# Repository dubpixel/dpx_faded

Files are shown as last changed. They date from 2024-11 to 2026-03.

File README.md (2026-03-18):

<!-- Improved compatibility of back to top link: See: https://github.com/othneildrew/Best-README-Template/pull/73 -->

<!--  *** Thanks for checking out the Best-README-Template. If you have a suggestion that would make this better, please fork the repo and create a pull request or simply open an issue with the tag "enhancement". Don't forget to give the project a star! Thanks again! Now go create something AMAZING! :D -->

<!-- /// d   u   b   p   i   x   e   l  ---  f   o   r   k   ////--v0.5.0 -->
<!--this has additionally been modifed by @dubpixel for hardware use -->
<!--search dpx_faded.. search & replace is COMMAND OPTION F -->

<!--todo add small product image thats not in a details tag -->
<!--igure out how to get the details tag to properly render in jekyll for gihub pages.-->

<!-- PROJECT SHIELDS -->
<!--
*** I'm using markdown "reference style" links for readability.
*** Reference links are enclosed in brackets [ ] instead of parentheses ( ).
*** See the bottom of this document for the declaration of the reference variables
*** for contributors-url, forks-url, etc. This is an optional, concise syntax you may use.
*** https://www.markdownguide.org/basic-syntax/#reference-style-links
***
-->
[][contributors-url]
[][forks-url]
[][stars-url]
[][issues-url]
[][license-url]
[][linkedin-url]

<!-- PROJECT LOGO -->
<br />
<div align="center">
  <a href="https://github.com/dubpixel/dpx_faded">
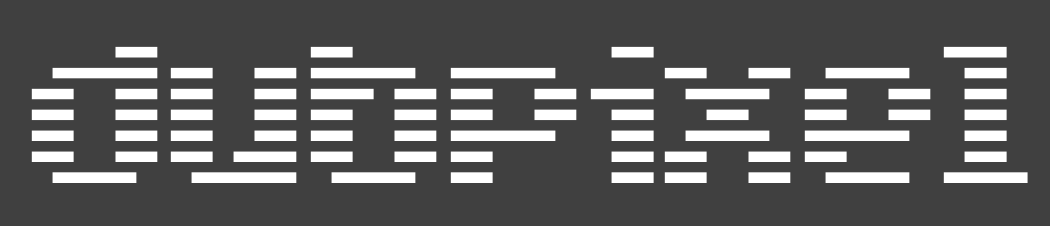
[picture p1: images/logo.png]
    
  </a>

<h1 align="center">dpx_faded</h1>
<h3 align="center"><i>because whats life without fader?</i></h3>
<br />
  <p align="center">
    ...a motorized fader breakout inspired by the FADER_4. Since there were only gerbers that didnt seem to match any faders available easily  - i re made a KiCAD project based on the 1.8 board revision. Included here for quick reference is a VScode migrated FADER_X firmware distro... soon to be migrated to its own _genuine_ fork.
        <br />
     »  
     <a href="https://github.com/dubpixel/dpx_faded/tree/main/"><strong>Project Here!</strong></a>
     »  
    <a href="https://github.com/dubpixel/dpx_faded/tree/main/hardware/src/dpx_faded/bom"><strong>BOM Here!</strong></a>
     » 
    <a href="https://dubpixel.github.io/dpx_faded/ibom/index.html"><strong>Interactive BOM Here!</strong></a>
     <br />
    <a href="https://github.com/dubpixel/dpx_faded/issues/new?labels=bug&template=bug-report---.md">Report Bug</a>
    ·
    <a href="https://github.com/dubpixel/dpx_faded/issues/new?labels=enhancement&template=feature-request---.md">Request Feature</a>
    </p>
</div>
   <br />
<!-- TABLE OF CONTENTS -->
<details>
<summary><h3>Table of Content</h3></summary>
<ol>
    <li>
      <a href="#about-the-project">About The Project</a>
      <ul>
        <li><a href="#built-with">Built With</a></li>
      </ul>
    </li>
    <li>
      <a href="#getting-started">Getting Started</a>
      <ul>
        <li><a href="#prerequisites">Prerequisites</a></li>
        <li><a href="#installation">Installation</a></li>
      </ul>
    </li>
    <li><a href="#usage">Usage</a></li>    
    <li><a href="#reflection">Reflection</a></li>
    <li><a href="#roadmap">Roadmap</a></li>
    <li><a href="#contributing">Contributing</a></li>
    <li><a href="#license">License</a></li>
    <li><a href="#contact">Contact</a></li>
    <li><a href="#acknowledgments">Acknowledgments</a></li>
</ol>
</details>
<br />
<!-- ABOUT THE PROJECT -->

<details>
<summary><h3>About The Project</h3></summary>
While the maker made the firmware open source, as well as the production gerber files - the cad files were not released in a malliable format, which doesnt allow further development of that hardware platform. (bummer). Since there is some community interest in the product, here we attempt to reverse engineer the FADE_4 as a proof of concept before continuing with development
</br>
author(s): // www.dubpixel.tv  - i@dubpixel.tv | other authors
</br>
<h3>Images</h3>

### FRONT
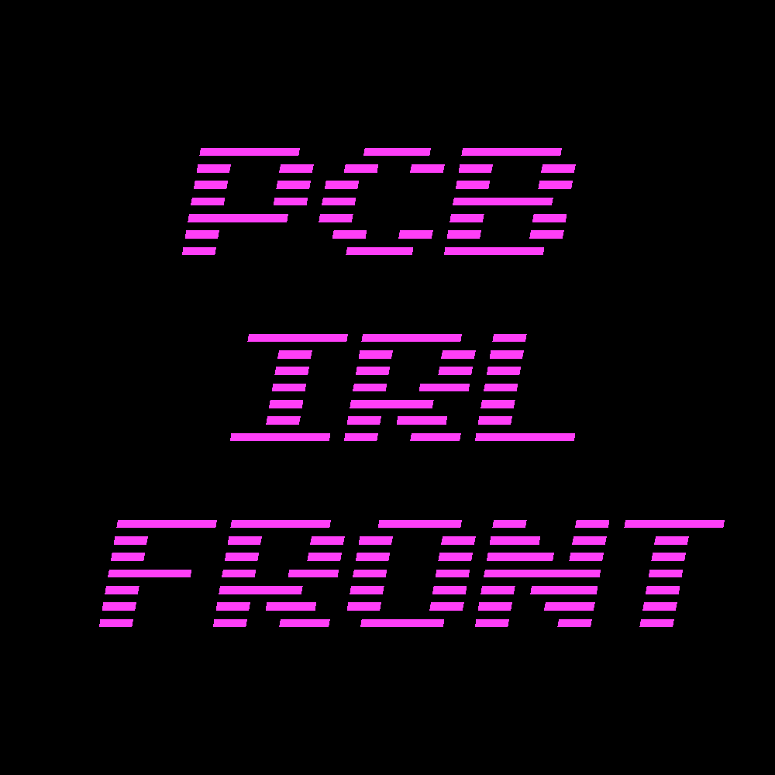
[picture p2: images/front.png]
FRONT


### REAR 
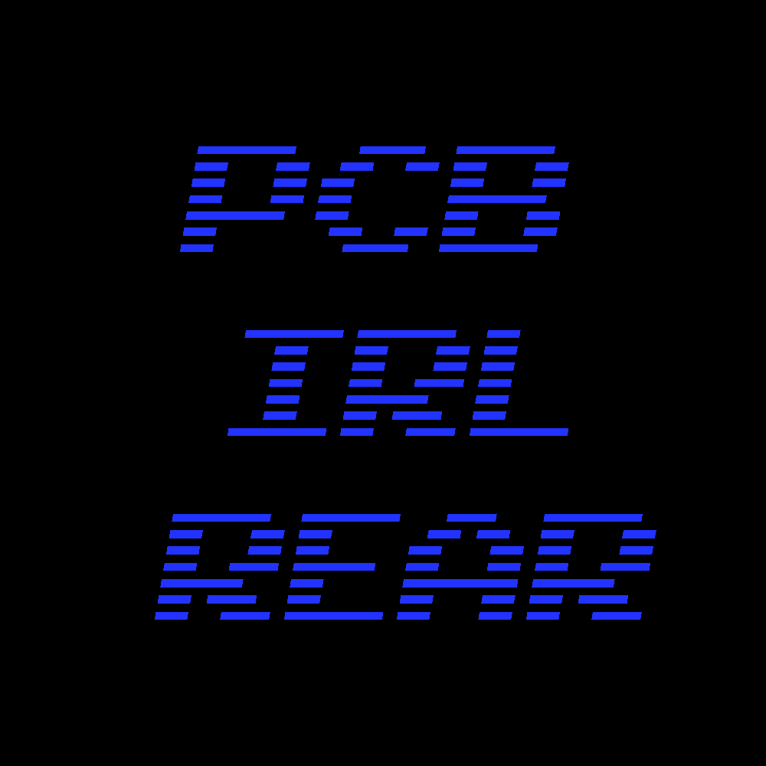
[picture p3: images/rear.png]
REAR


### FRONT Rendering
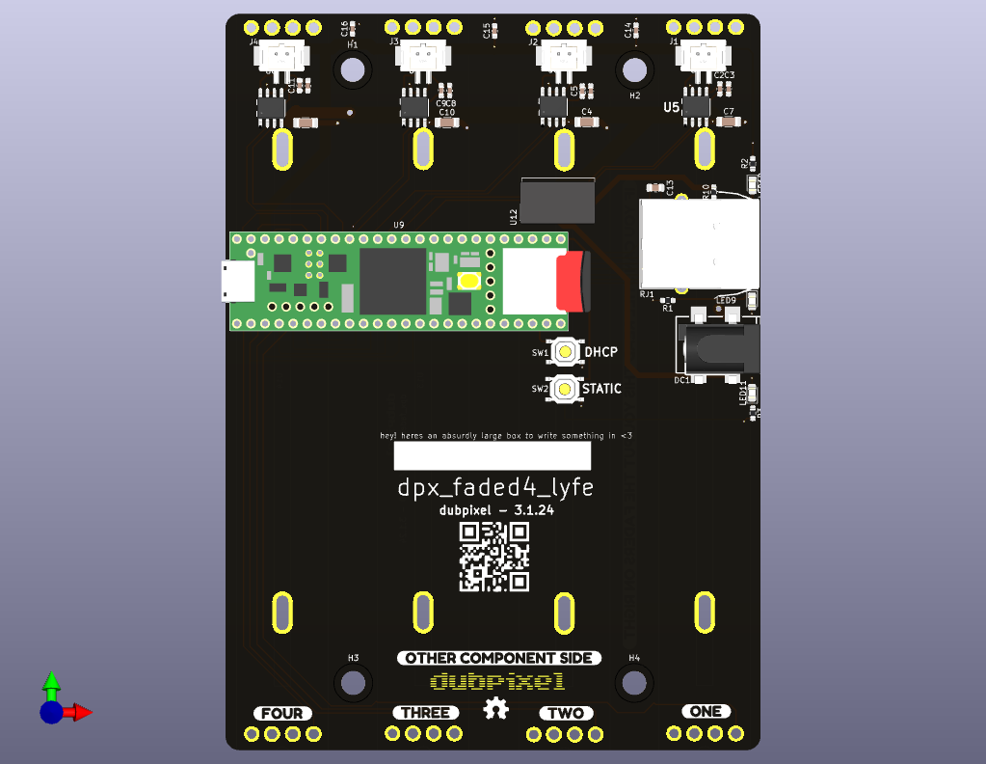
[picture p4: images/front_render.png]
FRONT


### REAR Rendering
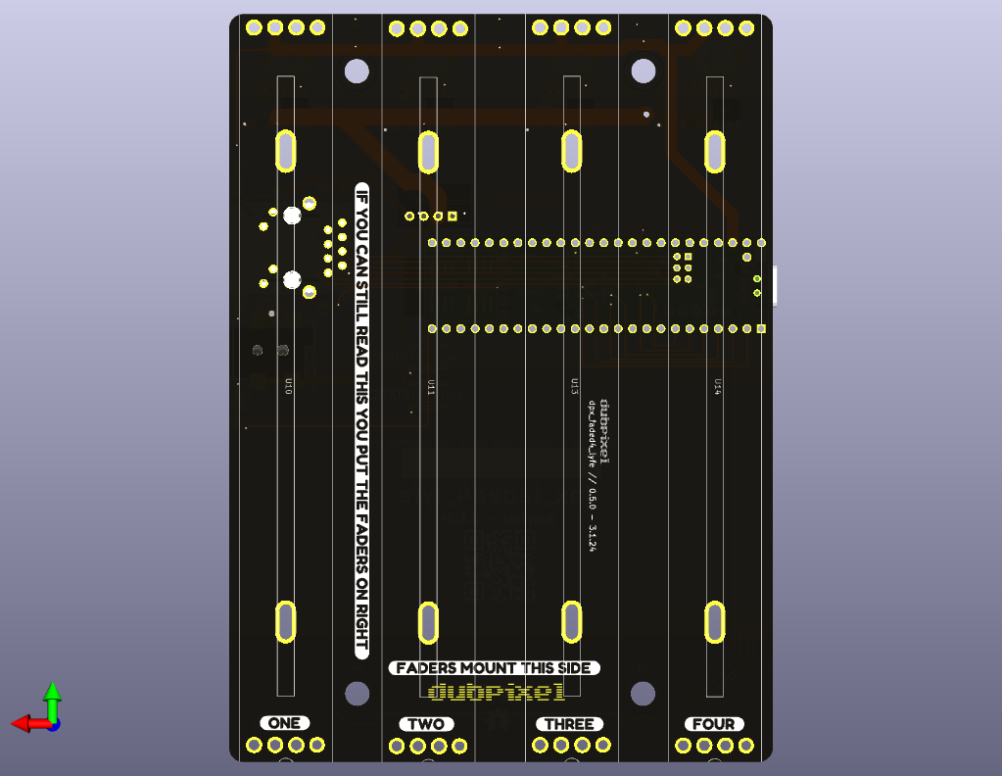
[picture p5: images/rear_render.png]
REAR


### iBOM PCB Front
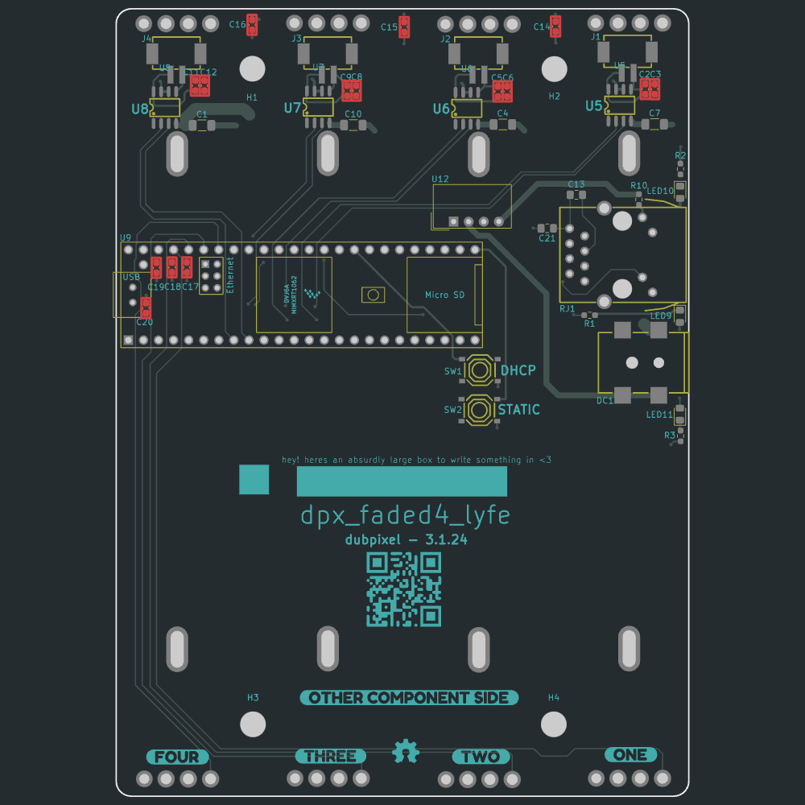
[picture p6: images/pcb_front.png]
iBOM Front


### iBOM PCB Rear
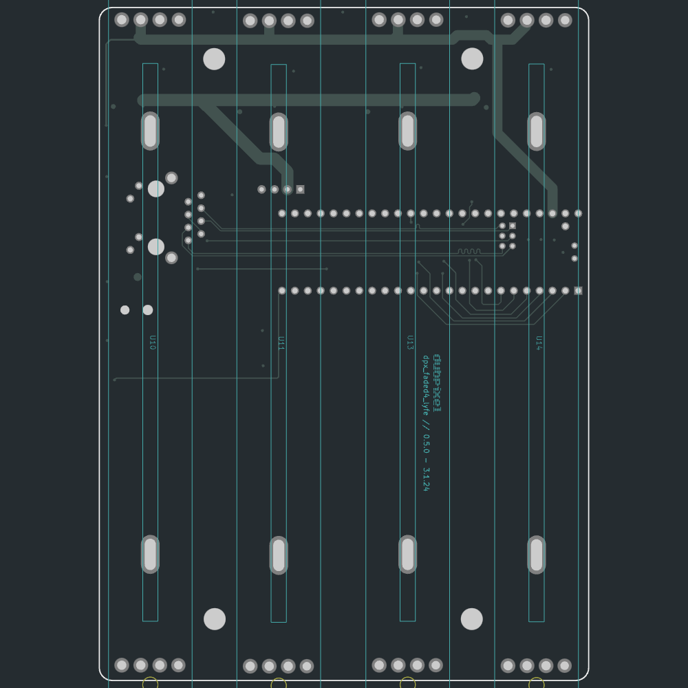
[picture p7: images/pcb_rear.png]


</details>

<p align="right">(<a href="#readme-top">back to top</a>)</p>

### Built With 
 * [][KiCad-url]
 * [][Autodesk-url]
 * [][FastLed-url]

<!--
  
 * [![Fusion360][Fusion-360]][Autodesk-url]
 * [![Next][Next.js]][Next-url]
 * [![React][React.js]][React-url]
 * [![Vue][Vue.js]][Vue-url]
 * [![Angular][Angular.io]][Angular-url]
 * [![Svelte][Svelte.dev]][Svelte-url]
 * [![Laravel][Laravel.com]][Laravel-url]
 * [![Bootstrap][Bootstrap.com]][Bootstrap-url]
 * [![JQuery][JQuery.com]][JQuery-url]
 
-->
<p align="right">(<a href="#readme-top">back to top</a>)</p>

<!-- GETTING STARTED -->
## Getting Started

### Prerequisites

### Installation

<!--
1. Download...
2. Enjoy.
3. Repeat as Needed! -->

<p align="right">(<a href="#readme-top">back to top</a>)</p>

<!-- USAGE EXAMPLES -->
## Usage

<!-- Use this space to show useful examples of how a project can be used. Additional screenshots, code examples and demos work well in this space. You may also link to more resources.

_For more examples, please refer to the [Documentation](https://example.com)_-->

<p align="right">(<a href="#readme-top">back to top</a>)</p>

## Reflection

* what did we learn? 
  - things take what they take. (good) things take more.
  - pinouts. always read the pinouts with parts on somoene elses BOM/hardware design
* what do we like/hate?
  - faders
  - the pinout from the fade 4 was kinda wack in the way that it forced me to do certain routing.
  - finally got the chance to do an on-the-board rj45 /  differential trace matching etc.
* what would/could we do differently?
 - wiper pin up top /  better routing of the analog pins, better use of the multilayer pcb

<!-- 
* what did we learn? 
* what do we like/hate?
* what would/could we do differently? 
-->

<p align="right">(<a href="#readme-top">back to top</a>)</p>

<!-- ROADMAP -->

## Roadmap

- [x] Reverse Enineer FADE_4 from gerber and firmware.
- [x] Re-Draw Front Panel
- [ ] Prove Existing FADE_4 Redesign 
    - [ ] with x32 faders
- [ ] Find source of touch faders from anyone but Apai
    - [ ] talking to lyric made me want to go be a dirt farmer
- [ ] Implement Touch sensors on faders
- [ ] Add additional control sets
  - [ ] X/y joystick
  - [ ] potentiometer
    - [ ] analog multiplexor for addtl analog ins
  - [ ] rotary encoder ?
  - [ ] adressable led
  - [ ] cherry keys / keymatrix

See the [open issues](https://github.com/dubpixel/dpx_faded/issues) for a full list of proposed features (and known issues).

<p align="right">(<a href="#readme-top">back to top</a>)</p>

<!-- CONTRIBUTING -->
## Contributing

Contributions are what make the open source community such an amazing place to learn, inspire, and create. Any contributions you make are **greatly appreciated**.

If you have a suggestion that would make this better, please fork the repo and create a pull request. You can also simply open an issue with the tag "enhancement".
Don't forget to give the project a star! Thanks again!

1. Fork the Project
2. Create your Feature Branch (`git checkout -b feature/AmazingFeature`)
3. Commit your Changes (`git commit -m 'Add some AmazingFeature'`)
4. Push to the Branch (`git push origin feature/AmazingFeature`)
5. Open a Pull Request

<p align="right">(<a href="#readme-top">back to top</a>)</p>

### Top contributors:

<a href="https://github.com/dubpixel/dpx_faded/graphs/contributors">
  contrib.rocks image
</a>

<!-- LICENSE -->
## License

  Distributed under the CERN Open Hardware Licence Version 2 - Strongly Reciprocal (CERN-OHL-S v2). See [`LICENSE`](LICENSE) for more information.

<p align="right">(<a href="#readme-top">back to top</a>)</p>

<!-- CONTACT -->
## Contact

  ### Joshua Fleitell - i@dubpixel.tv

  Project Link: [https://github.com/dubpixel/dpx_faded](https://github.com/dubpixel/dpx_faded)

<p align="right">(<a href="#readme-top">back to top</a>)</p>

<!-- ACKNOWLEDGMENTS -->
## Acknowledgments

* [stagehacks](https://github.com/stagehacks/FADER_X) - fader X project

<!--
  * [ ]() - the best 
-->

<p align="right">(<a href="#readme-top">back to top</a>)</p>

<!-- MARKDOWN LINKS & IMAGES -->
<!-- https://www.markdownguide.org/basic-syntax/#reference-style-links -->
[contributors-shield]: https://img.shields.io/github/contributors/dubpixel/dpx_faded.svg?style=for-the-badge
[contributors-url]: https://github.com/dubpixel/dpx_faded/graphs/contributors
[forks-shield]: https://img.shields.io/github/forks/gdubpixel/dpx_faded.svg?style=for-the-badge
[forks-url]: https://github.com/dubpixel/dpx_faded/network/members
[stars-shield]: https://img.shields.io/github/stars/dubpixel/dpx_faded.svg?style=for-the-badge
[stars-url]: https://github.com/dubpixel/dpx_faded/stargazers
[issues-shield]: https://img.shields.io/github/issues/dubpixel/dpx_faded.svg?style=for-the-badge
[issues-url]: https://github.com/dubpixel/dpx_faded/issues
[license-shield]: https://img.shields.io/badge/license-CERN--OHL--S--2.0-blue?style=for-the-badge
[license-url]: https://github.com/dubpixel/dpx_faded/blob/main/LICENSE
[linkedin-shield]: https://img.shields.io/badge/-LinkedIn-black.svg?style=for-the-badge&logo=linkedin&colorB=555
[linkedin-url]: https://linkedin.com/in/jfleitell
[product-front]: images/front.png
[product-rear]: images/rear.png
[product-front-rendering]: images/front_render.png
[product-rear-rendering]: images/rear_render.png
[product-pcbFront]: images/pcb_front.png
[product-pcbRear]: images/pcb_rear.png
[Next.js]: https://img.shields.io/badge/next.js-000000?style=for-the-badge&logo=nextdotjs&logoColor=white
[Next-url]: https://nextjs.org/
[React.js]: https://img.shields.io/badge/React-20232A?style=for-the-badge&logo=react&logoColor=61DAFB
[React-url]: https://reactjs.org/
[Vue.js]: https://img.shields.io/badge/Vue.js-35495E?style=for-the-badge&logo=vuedotjs&logoColor=4FC08D
[Vue-url]: https://vuejs.org/
[Angular.io]: https://img.shields.io/badge/Angular-DD0031?style=for-the-badge&logo=angular&logoColor=white
[Angular-url]: https://angular.io/
[Svelte.dev]: https://img.shields.io/badge/Svelte-4A4A55?style=for-the-badge&logo=svelte&logoColor=FF3E00
[Svelte-url]: https://svelte.dev/
[Laravel.com]: https://img.shields.io/badge/Laravel-FF2D20?style=for-the-badge&logo=laravel&logoColor=white
[Laravel-url]: https://laravel.com
[Bootstrap.com]: https://img.shields.io/badge/Bootstrap-563D7C?style=for-the-badge&logo=bootstrap&logoColor=white
[Bootstrap-url]: https://getbootstrap.com
[JQuery.com]: https://img.shields.io/badge/jQuery-0769AD?style=for-the-badge&logo=jquery&logoColor=white
[JQuery-url]: https://jquery.com 
[KiCad.org]: https://img.shields.io/badge/KiCad-v8.0.6-blue
[KiCad-url]: https://kicad.org 
[Fusion-360]: https://img.shields.io/badge/Fusion360-v4.2.0-green
[Autodesk-url]: https://autodesk.com 
[FastLed.io]: https://img.shields.io/badge/FastLED-v3.9.9-red
[FastLed-url]: https://fastled.io

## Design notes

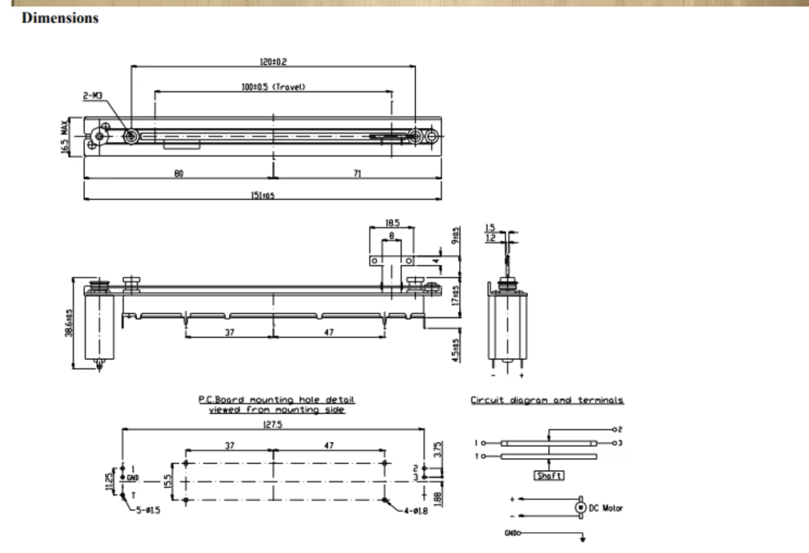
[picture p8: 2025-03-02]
hardware/spec/datasheet/1-APAI - SC1009M B10K 13T/APAISC100M_from_website.png

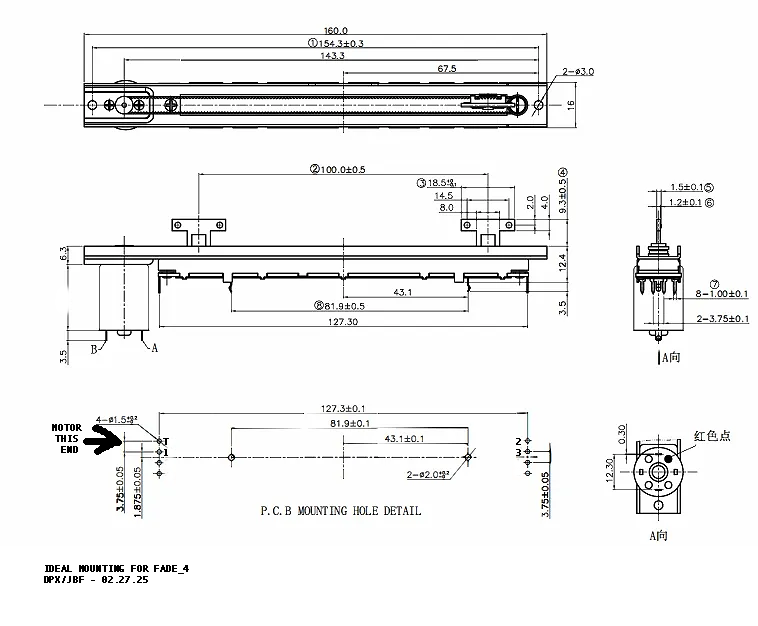
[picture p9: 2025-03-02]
hardware/spec/datasheet/PINOUT_COMPARISONS/IDEAL_DIMENSIONS_FROM_FADE4_sharp-2.png

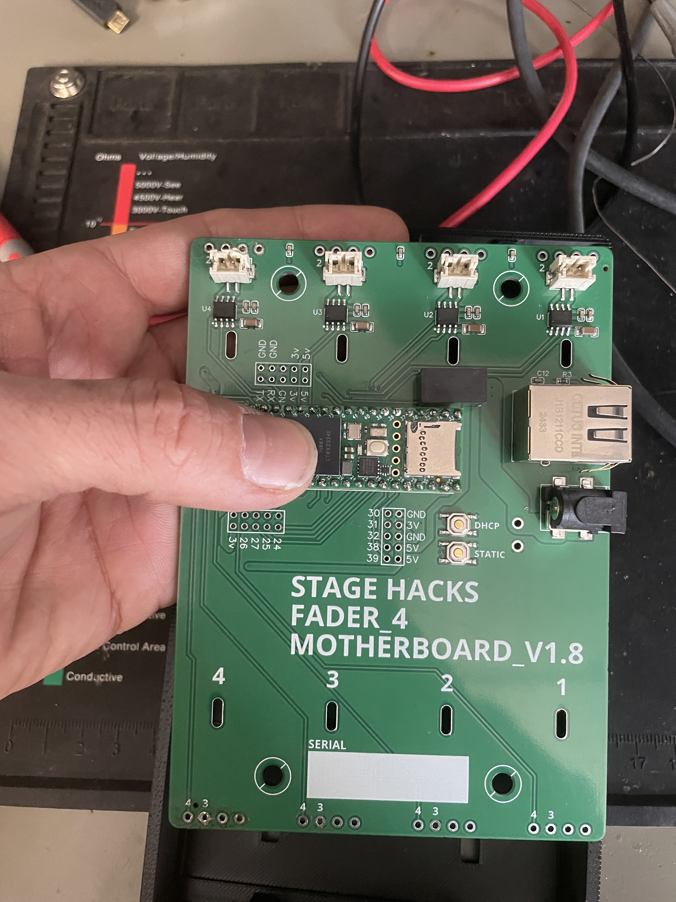
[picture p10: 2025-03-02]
hardware/spec/datasheet/photos_of_things/fade4_pcb_reverse.jpeg

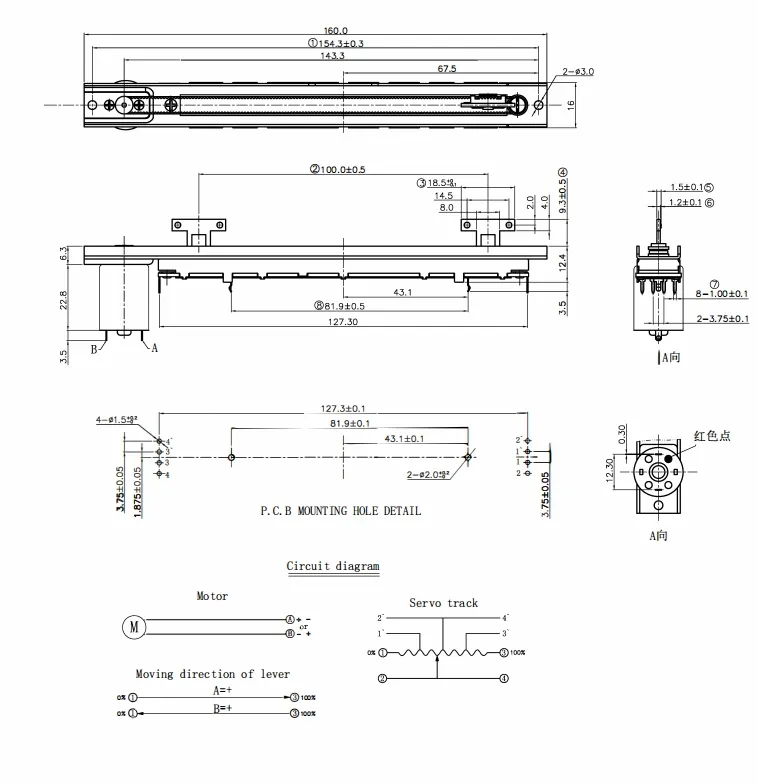
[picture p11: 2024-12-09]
hardware/spec/datasheet/3-terwinx32/terwin_x32.webp

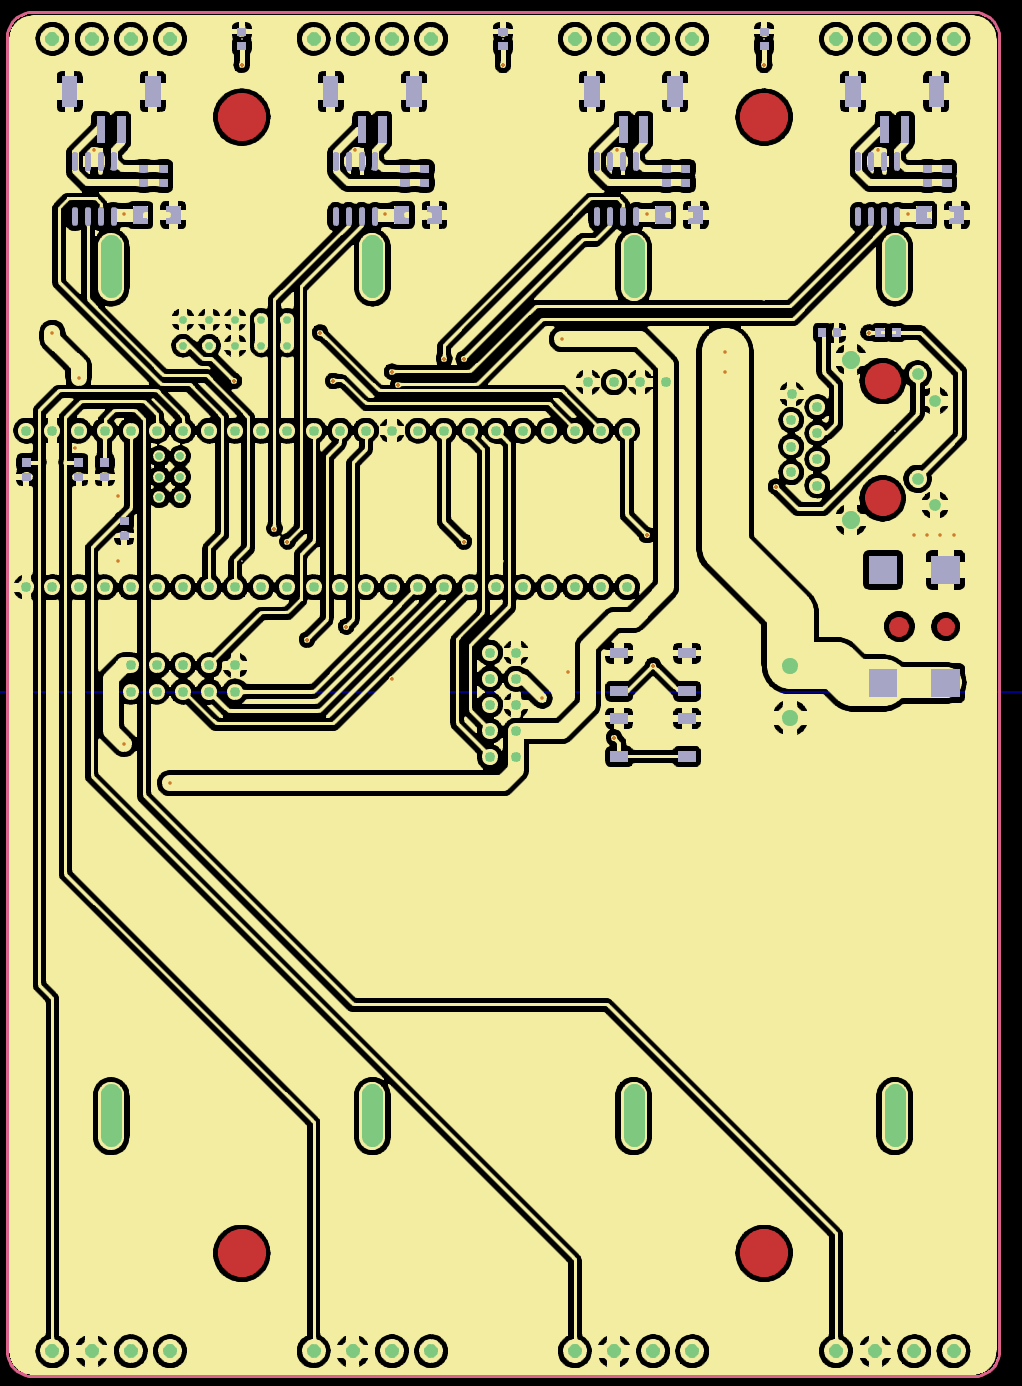
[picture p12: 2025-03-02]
hardware/spec/datasheet/photos_of_things/fade4_silkscreen.png

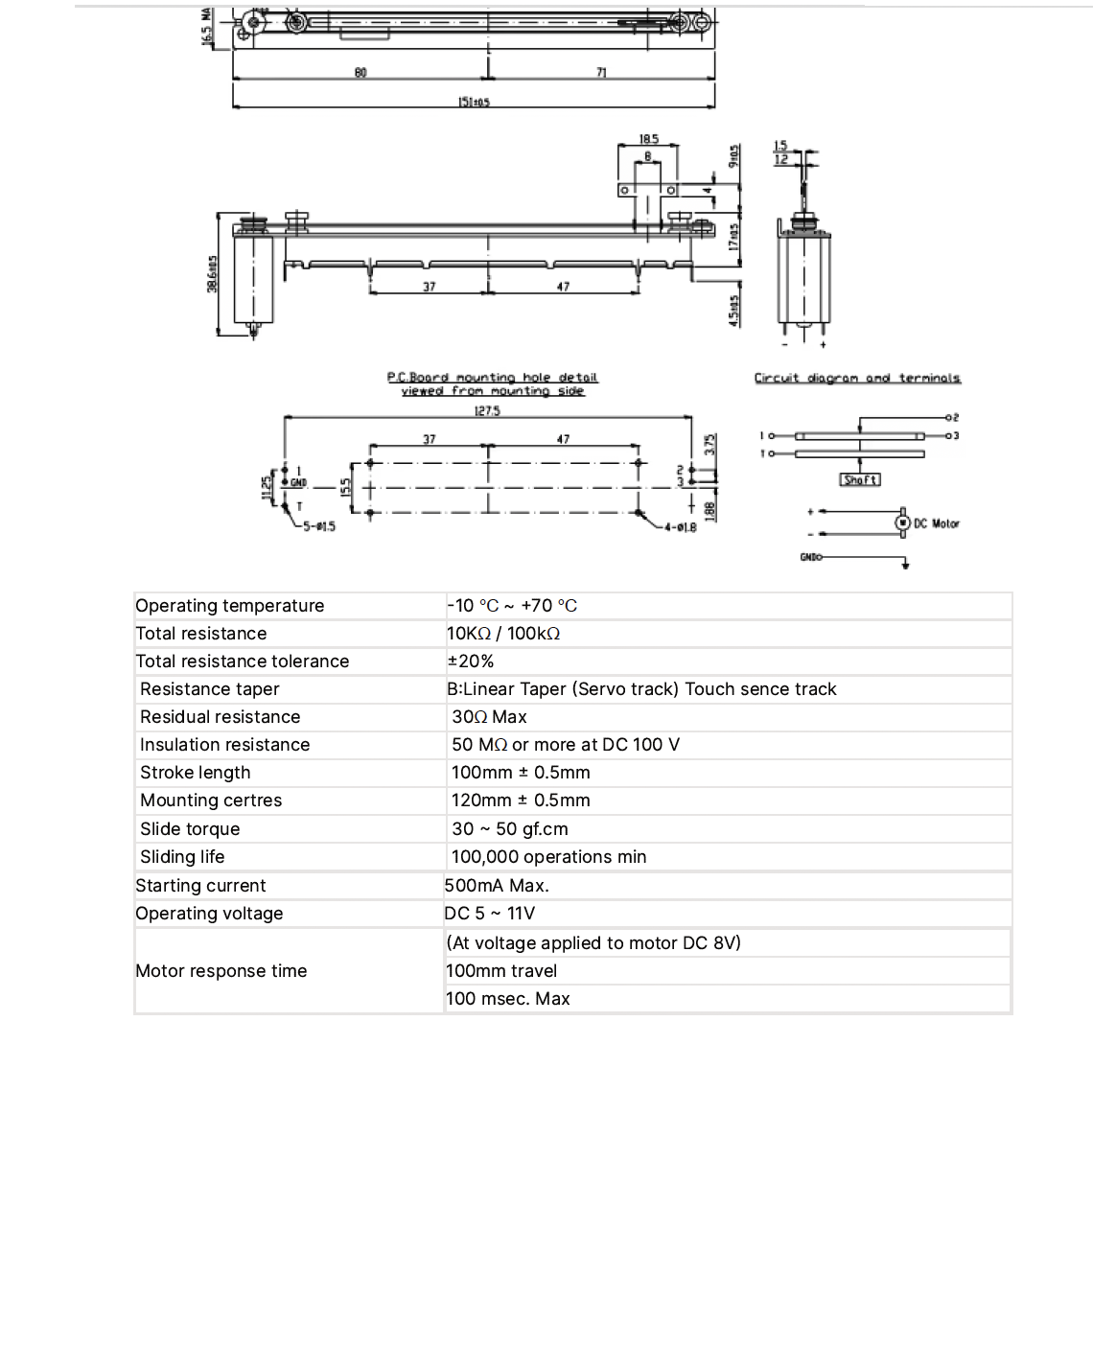
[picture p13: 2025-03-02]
hardware/spec/datasheet/1-APAI - SC1009M B10K 13T/apai_fader_drama/apai_fader_mess_screenshot.png

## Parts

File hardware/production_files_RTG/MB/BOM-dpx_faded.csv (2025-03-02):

Comment | Designator | Footprint | LCSC | Quantity
100 NF | C11,C12,C13,C14,C15,C16,C17,C18,C19,C2,C20,C21,C3,C5,C6,C8,C9 | C_0603_1608Metric_Pad1.08x0.95mm_HandSolder | C14663 | 17
YELLO | LED11 | LED_0805_2012Metric_Pad1.15x1.40mm_HandSolder | C2296 | 1
GREEN | LED10 | LED_0805_2012Metric_Pad1.15x1.40mm_HandSolder | C2297 | 1
680R | R1,R10,R2,R3 | R_0603_1608Metric_Pad0.98x0.95mm_HandSolder | C23228 | 4
4.7 uF | C1,C10,C4,C7 | C_1206_3216Metric_Pad1.33x1.80mm_HandSolder | C29823 | 4
TS-1187A-B-A-B | SW1,SW2 | SW-SMD_4P-L5.1-W5.1-P3.70-LS6.5-TL_H1.5 | C318884 | 2
DC-005-5A-2.0-SMT | DC1 | DC-IN-TH_DC-005-5A-2.0-SMT | C319134 | 1
motor.1 | J1,J2,J3,J4 | CONN-SMD_PH2.0-1X2PW | C64658 | 4
RED | LED9 | LED_0805_2012Metric_Pad1.15x1.40mm_HandSolder | C84256 | 1
TC118S | U5,U6,U7,U8 | SOP-8_L4.9-W3.9-P1.27-LS6.0-BL | C88308 | 4
J1B1211CCD | RJ1 | RJ45-TH_J1B1211CCD | C910371 | 1
NML0505SC | U12 | NML0505SC |  | 1
Teensy4.1 | U9 | Teensy41_less_pins |  | 1
~ | U14 | Fader_behringerx32_b10k_100mm |  | 1
~ | U11 | Fader_behringerx32_b10k_100mm |  | 1
~ | U10 | Fader_behringerx32_b10k_100mm |  | 1
~ | U13 | Fader_behringerx32_b10k_100mm |  | 1

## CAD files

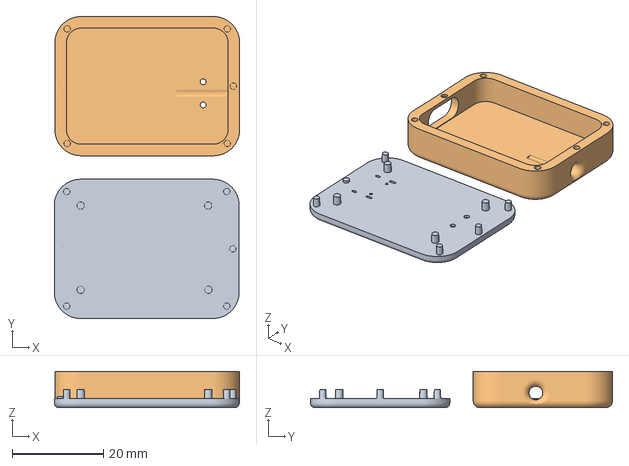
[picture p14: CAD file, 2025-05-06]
hardware/3d/FADER_4 Enclosure.3mf
40.7 x 66.3 x 8.00 mm
dpx_pdPooper-Bottom.stl
dpx_pdxPooper-Lid.stl

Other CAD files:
hardware/3d/FADER_4 Enclosure.stl

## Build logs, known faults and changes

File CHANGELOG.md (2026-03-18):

# Changelog

## v0.7.0 — 2026-03-17

### Added or Changed
- Re-licensed under CERN Open Hardware Licence Version 2 - Strongly Reciprocal (CERN-OHL-S v2)
- Added LICENSE file
- All versions from v0.7.0 forward are under CERN-OHL-S v2

### Removed
- UNLICENSE / MIT license references (firmware was always separate)

---

## v0.0.0

### Added or Changed
- 

### Removed

-

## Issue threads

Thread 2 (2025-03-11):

adjust silkscreen and add pin numbers

dubpixel, 2025-03-11:
## Summary
have pin numbesrs of the faders on the siklscreen on both sides.

### Motivation
clarity, easier to see if you can just flip the fader

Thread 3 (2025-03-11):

Fader Pin holes a bit too roomy

dubpixel, 2025-03-11:
## Describe the bug
the fader pin holes could size down a hair

### Expected behavior
the could fit a bit more snug

### Additional context
other mounting hole positions seem to be fine

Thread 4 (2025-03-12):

DHCP button not on pin 40

dubpixel, 2025-03-12:
## Describe the bug
DHCP Button was mis wired to 41.  firmware needed to be adjusted to make it work

### Expected behavior
DHCP button should be wired to 40

### Additional context
wire it to 40 to keep it in line with last release of fade_X

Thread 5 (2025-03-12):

LED are all backwards

dubpixel, 2025-03-12:
## Describe the bug
all of the indicator led are placed backwards, because the silkscreen symbol  says where the gnd pin is, is actually +

### Steps to reproduce
checked the symbol to footprint path - the footrpint was broken

### Expected behavior
pin 2 is A pin 1 ia K... not the other way.

### Additional context
updated the symbol to match everyone else logic

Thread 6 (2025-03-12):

SW1 & SW2 swapped

dubpixel, 2025-03-12:
## Describe the bug
the label for sw1 and sw 2 are incorrect / swapped. shoud be in line with the variables declared in the function

### Steps to reproduce
read the code, see what button 1 and button 2 do.

### Expected behavior
SW2 is for DHCP SW1 is for STATIC   - even tho the button positions are logical that they would be otherwise.

### Additional context
none.

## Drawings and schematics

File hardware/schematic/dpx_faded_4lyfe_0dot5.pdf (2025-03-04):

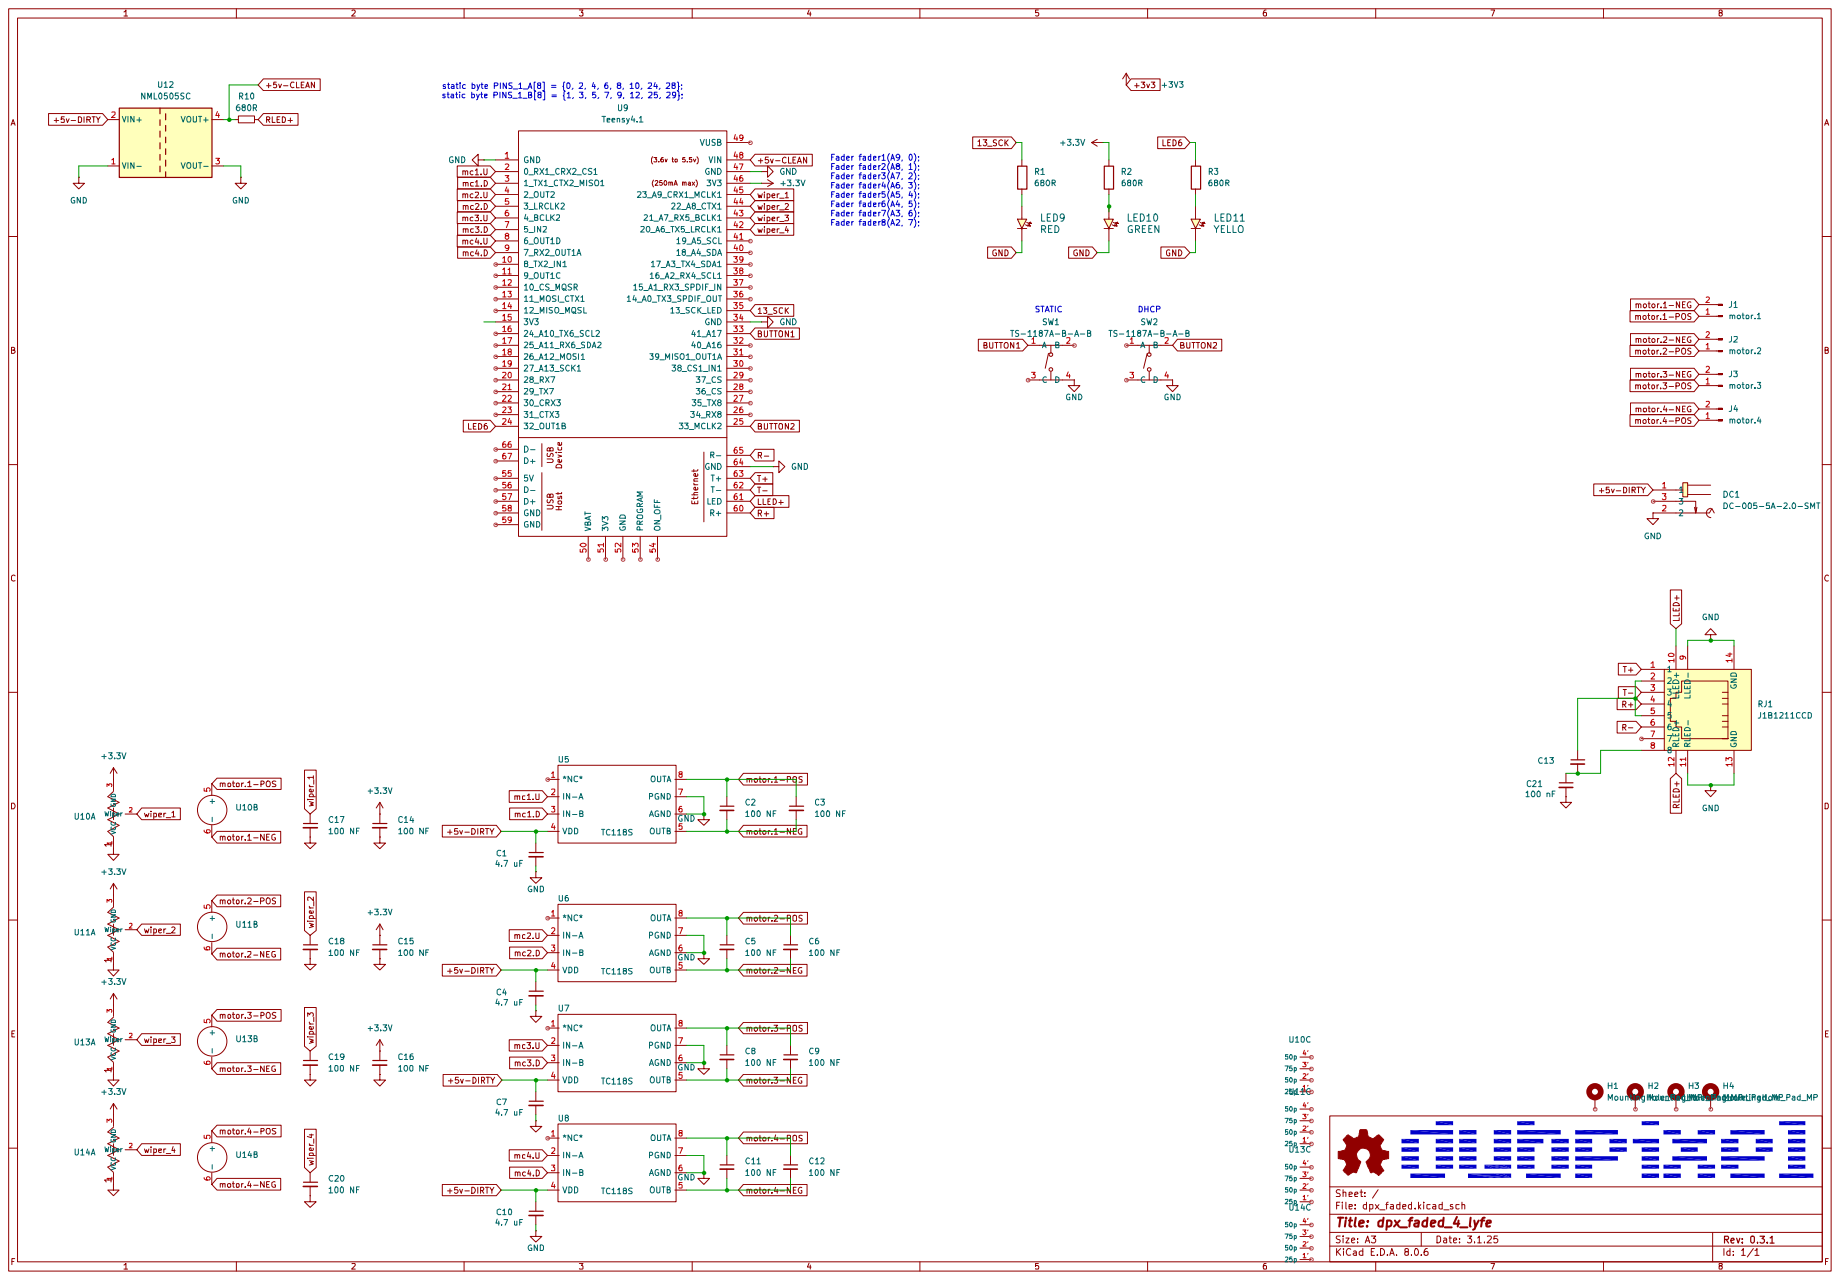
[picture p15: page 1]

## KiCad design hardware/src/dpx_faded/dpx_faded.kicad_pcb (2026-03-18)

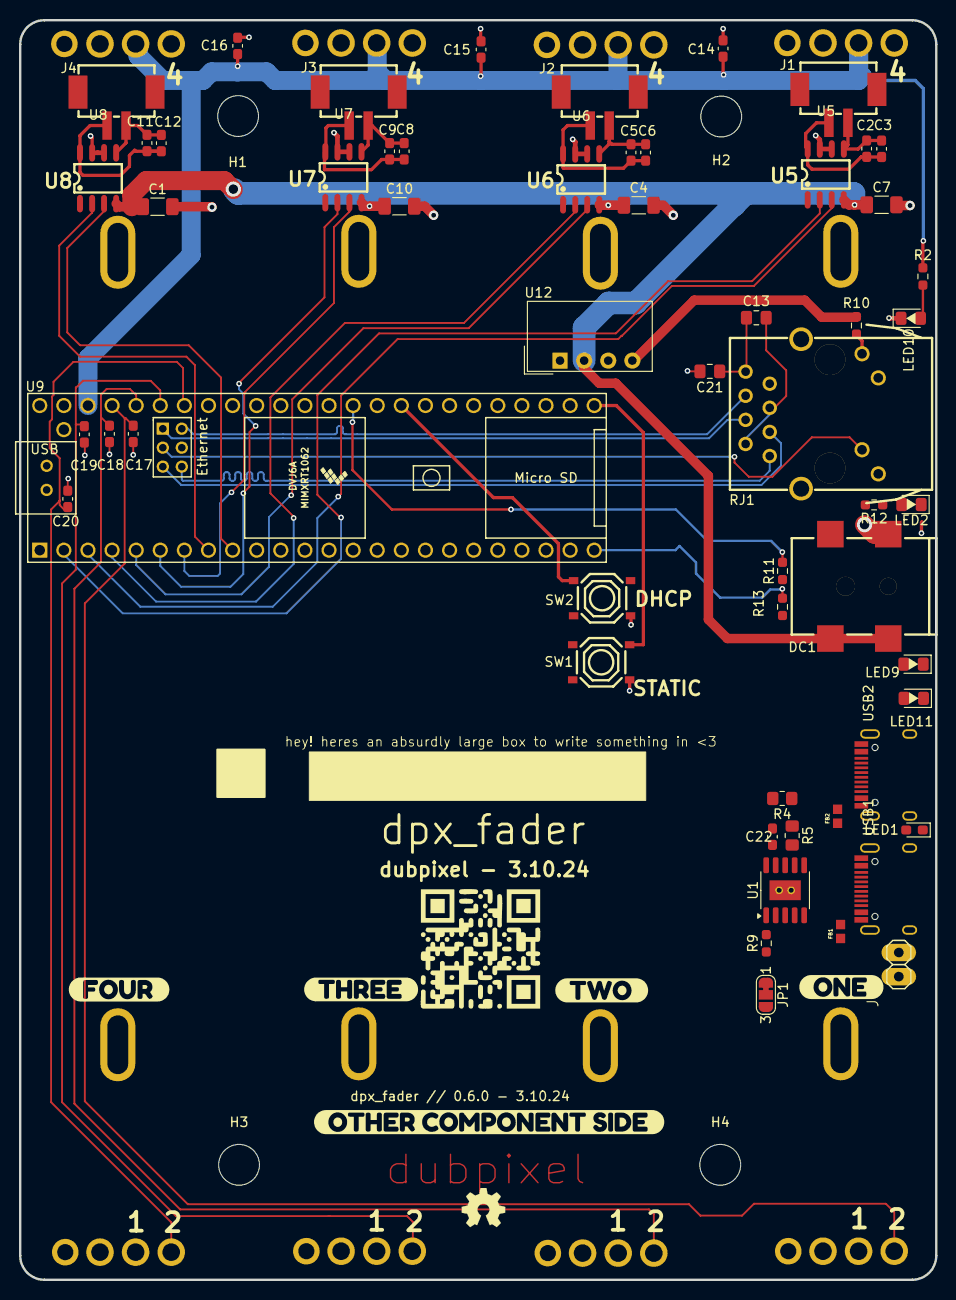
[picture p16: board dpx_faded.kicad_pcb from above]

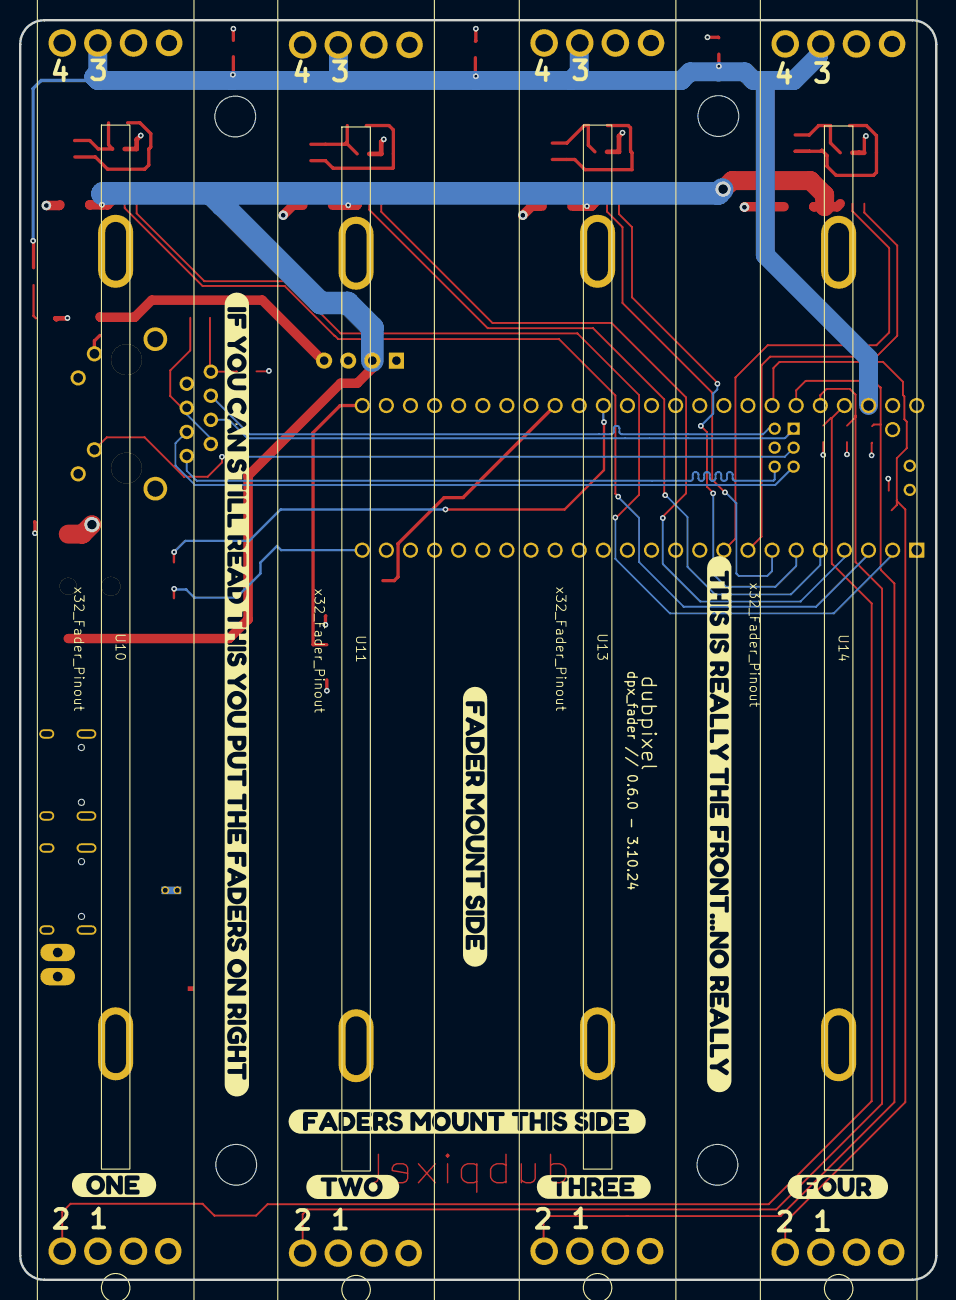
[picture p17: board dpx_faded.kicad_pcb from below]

Board: 4 copper layers, 96.5 x 132.7 mm, 78 parts (12 on the bottom side), 56 nets.

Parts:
C1, C4, C7, C10: 4.7 uF; C_1206_3216Metric_Pad1.33x1.80mm_HandSolder
C2, C3, C5, C6, C8, C9, C11, C12, C14, C15, C16, C17, C18, C19, C20: 100 NF; C_0603_1608Metric_Pad1.08x0.95mm_HandSolder
C13, C21: 100 nF; C_0805_2012Metric_Pad1.18x1.45mm_HandSolder
C22: 1 uF; C_0603_1608Metric_Pad1.08x0.95mm_HandSolder
DC1: DC-005-5A-2.0-SMT; DC-IN-TH_DC-005-5A-2.0-SMT
FB1, FB2: 220h 110mHz; FERRITE_0603
H1, H2, H3, H4: MountingHole_Pad_MP; MountingHole_4.3mm_M4_ISO14580
J1: motor.1; CONN-SMD_PH2.0-1X2PW
J2: motor.2; CONN-SMD_PH2.0-1X2PW
J3: motor.3; CONN-SMD_PH2.0-1X2PW
J4: motor.4; CONN-SMD_PH2.0-1X2PW
J5: Conn_01x02_Pin; 1X02
JP1: Jumper_3_Bridged12; SolderJumper-3_P1.3mm_Bridged12_RoundedPad1.0x1.5mm_NumberL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
LED1: RED; LED_0603_1608Metric_Pad1.05x0.95mm_HandSolder
LED2: GREEN; LED_0805_2012Metric_Pad1.15x1.40mm_HandSolder
LED9: RED; LED_0805_2012Metric_Pad1.15x1.40mm_HandSolder
LED10: YELLO; LED_0805_2012Metric_Pad1.15x1.40mm_HandSolder
LED11: WHITE; LED_0805_2012Metric_Pad1.15x1.40mm_HandSolder
R2: 65R; R_0603_1608Metric_Pad0.98x0.95mm_HandSolder
R4: 1k; R_0805_2012Metric_Pad1.20x1.40mm_HandSolder
R5: 10k; R_0805_2012Metric_Pad1.20x1.40mm_HandSolder
R9, R12, R13: 120R; R_0603_1608Metric_Pad0.98x0.95mm_HandSolder
R10: 680R; R_0603_1608Metric_Pad0.98x0.95mm_HandSolder
R11: 75R; R_0603_1608Metric_Pad0.98x0.95mm_HandSolder
RJ1: J1B1211CCD; RJ45-TH_J1B1211CCD
SW1, SW2: TS-1187A-B-A-B; SW-SMD_4P-L5.1-W5.1-P3.70-LS6.5-TL_H1.5
SYM1: Logo_Open_Hardware_Small; OSHW-LogoNT_7.3x6mm_Silk
U1: CH224K; SSOP-10-1EP_3.9x4.9mm_P1mm_EP2.1x3.3mm_ThermalVias
U5, U6, U7, U8: TC118S; SOP-8_L4.9-W3.9-P1.27-LS6.0-BL
U9: Teensy4.1; Teensy41_less_pins
U10, U11, U13, U14: Fader_behringerx32_b10k_100mm
U12: NML0505SC
USB1, USB2: HRO-TYPE-C-31-M-12; HRO-TYPE-C-31-M-12-Assembly
kibuzzard-67C3BB4B: G***; kibuzzard-67C3BB4B
kibuzzard-67C38A3C: G***; kibuzzard-67C38A3C
kibuzzard-67C38B05: G***; kibuzzard-67C38B05
kibuzzard-67C38035, kibuzzard-67C38035#2: G***; kibuzzard-67C38035
kibuzzard-67C38056, kibuzzard-67C38056#2: G***; kibuzzard-67C38056
kibuzzard-67C38062, kibuzzard-67C38062#2: G***; kibuzzard-67C38062
kibuzzard-67C38072, kibuzzard-67C38072#2: G***; kibuzzard-67C38072
kibuzzard-67CFB29D: G***; kibuzzard-67CFB29D
kibuzzard-67D0F279: G***; kibuzzard-67D0F279

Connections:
13_SCK: R11.2, U9.35 (13_SCK_LED)
+3.3V: C14.1, C15.1, C16.1, R2.2, U9.46 (3V3), U10.3 (GND), U11.3 (GND), U13.3 (GND), U14.3 (GND)
+5v-CLEAN: R10.2, U9.48 (VIN), U12.4 (VOUT+)
+5v-DIRTY: C1.1, C4.1, C7.1, C10.1, DC1.1, U5.4 (VDD), U6.4 (VDD), U7.4 (VDD), U8.4 (VDD)
BUTTON1: SW2.1 (A), U9.33 (41_A17)
BUTTON2: SW1.2 (B), U9.25 (33_MCLK2)
CC1: U1.7 (CC1), USB1.4 (CC1), USB2.4 (CC1)
CC2: U1.6 (CC2), USB1.10 (CC2), USB2.10 (CC2)
D+: U1.4 (D+), USB1.6 (DP1), USB1.8 (DP2)
D+2: U9.67 (D+), USB2.6 (DP1), USB2.8 (DP2)
D-: U1.5 (D-), USB1.5 (DN2), USB1.7 (DN1)
D-2: U9.66 (D-), USB2.5 (DN2), USB2.7 (DN1)
GND: C1.2, C4.2, C7.2, C10.2, C14.2, C15.2, C16.2, C17.2, C18.2, C19.2, C20.2, C21.2, C22.2, DC1.2, FB1.2, FB2.2, J5.2, LED2.1 (C), LED9.1 (C), LED10.1 (C), LED11.1 (C), RJ1.9 (LLED-), RJ1.11 (RLED-), RJ1.13 (GND), RJ1.14 (GND), SW1.4 (D), SW2.4 (D), U1.11 (GND), U5.6 (AGND), U5.7 (PGND), U6.6 (AGND), U6.7 (PGND), U7.6 (AGND), U7.7 (PGND), U8.6 (AGND), U8.7 (PGND), U9.1 (GND), U9.34 (GND), U9.47 (GND), U9.64 (GND), U10.1 (VCC), U11.1 (VCC), U12.1 (VIN-), U12.3 (VOUT-), U13.1 (VCC), U14.1 (VCC), USB1.1 (GND), USB1.12 (GND), USB2.1 (GND), USB2.12 (GND)
LED6: R13.2, U9.24 (32_OUT1B)
LLED+: RJ1.10 (LLED+), U9.61 (LED)
unnamed: C13.1, RJ1.2, RJ1.5
unnamed: C13.2, C21.1, RJ1.8
unnamed: J5.1, JP1.3 (B)
unnamed: JP1.2 (C), U12.2 (VIN+)
unnamed: LED1.2 (A), R9.1
unnamed: LED2.2 (A), R12.1
unnamed: LED9.2 (A), R11.1
unnamed: LED10.2 (A), R2.1
unnamed: LED11.2 (A), R13.1
unnamed: R5.2, U1.8 (VBUS)
unnamed: FB1.1, USB1.13 (SHIELD)
unnamed: FB2.1, USB2.13 (SHIELD)
PG: LED1.1 (C), U1.10 (PG)
R+: RJ1.4, U9.60 (R+)
R-: RJ1.6, U9.65 (R-)
RLED+: R10.1, RJ1.12 (RLED+)
T+: RJ1.1, U9.63 (T+)
T-: RJ1.3, U9.62 (T-)
VBUS: JP1.1 (A), R4.1, R5.1, USB1.2 (VBUS), USB1.11 (VBUS)
VBUS_uC: U9.49 (VUSB), USB2.2 (VBUS), USB2.11 (VBUS)
VDD: C22.1, R4.2, R9.2, U1.1 (VDD), U1.9 (CFG1)
mc1.D: U5.3 (IN-B), U9.3 (1_TX1_CTX2_MISO1)
mc1.U: U5.2 (IN-A), U9.2 (0_RX1_CRX2_CS1)
mc2.D: U6.3 (IN-B), U9.5 (3_LRCLK2)
mc2.U: U6.2 (IN-A), U9.4 (2_OUT2)
mc3.D: U7.3 (IN-B), U9.7 (5_IN2)
mc3.U: U7.2 (IN-A), U9.6 (4_BCLK2)
mc4.D: U8.3 (IN-B), U9.9 (7_RX2_OUT1A)
mc4.U: U8.2 (IN-A), U9.8 (6_OUT1D)
motor.1-NEG: C2.2, C3.2, J1.2, U5.5 (OUTB)
motor.1-POS: C2.1, C3.1, J1.1, U5.8 (OUTA)
motor.2-NEG: C5.2, C6.2, J2.2, U6.5 (OUTB)
motor.2-POS: C5.1, C6.1, J2.1, U6.8 (OUTA)
motor.3-NEG: C8.2, C9.2, J3.2, U7.5 (OUTB)
motor.3-POS: C8.1, C9.1, J3.1, U7.8 (OUTA)
motor.4-NEG: C11.2, C12.2, J4.2, U8.5 (OUTB)
motor.4-POS: C11.1, C12.1, J4.1, U8.8 (OUTA)
wiper_1: C17.1, U9.45 (23_A9_CRX1_MCLK1), U10.2 (Wiper), U10.4
wiper_2: C18.1, U9.44 (22_A8_CTX1), U11.2 (Wiper), U11.4
wiper_3: C19.1, U9.43 (21_A7_RX5_BCLK1), U13.2 (Wiper), U13.4
wiper_4: C20.1, U9.42 (20_A6_TX5_LRCLK1), U14.2 (Wiper), U14.4

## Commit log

2024-11-13 images, mfg files, readme
    updated pcb renderings, files for mfg and the readme
    [BOM-dpx_faded.csv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]
2025-03-01 so much source and so much datasheet
    lots of fader drama
    gonna fork the design and reduce featureset, add x32 faders due to availa
    basically make a FADE_4 clone first because well - that whole thing has turned into the mystery project
    [BOM_F4MB-18_2023-07-03.csv, FADER_4 Enclosure.stl, PickAndPlace_F4MB-18_2023-07-03.csv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]
2025-03-02 first release
    ** big reorganize
    ++ version 1.0 of FADED4_LYFE based on v1.8 of FADE4
    ++ lots of fader related spec sheets.
    --remove backup files and other erratta
    [BOM-dpx_faded.csv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]
2025-03-02 Update README.md
    ** fix link to bom directory
2025-03-02 bom rearrange + production files
    ** copy a bom to a place
    ++ added production files (even though i thought we had?)
    [BOM-dpx_faded.csv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]
2025-03-02 Update README.md
    ** take two on the bom pathj
2025-03-03 panel files, rearrange most recent produciton files
    ++ front panel
    ** re-arrange production file
    [BOM-dpx_faded.csv, BOM-dpx_faded_FP.csv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]
2025-03-04 schematic
    ** clean up schematic
    ++ pdf of schematic
    [dpx_faded.kicad_sch]
2025-03-09 specs and cleaned up schematic
2025-05-06 post v0.5.0 fixes--->(v0.6.0)
    -----//HARDWARE
    ++ CH244 PD controller rough in
    ++ update PCB
    ++ add pdf for a fader
    -----//FIRMWARE
    ++ add maxpatch to test faders
    [dpx_faded.kicad_sch]
2025-05-06 firmware and hardware fixes
    -------//FIRMWARE
    ** changed static/reset ip to 10.0 values (see reset.ino&WebServerApply.Ino) 10.0.10.130 & sending to 10.0.10.120
    ++ added maxpatch to test midi / motor functionality
    ++ 3mf for the enclosure
    ------//HARDWARE
    ** corrected some LED pinout shiz, other stuff.
    [FADER_4 Enclosure.3mf, dpx_faded.kicad_pcb, dpx_faded.kicad_sch]
2026-03-18 refresh base files and push some pcb stuff
    [dpx_faded.kicad_pcb, dpx_faded.kicad_sch]
2026-03-18 v0.7.0 — re-license to CERN-OHL-S v2
